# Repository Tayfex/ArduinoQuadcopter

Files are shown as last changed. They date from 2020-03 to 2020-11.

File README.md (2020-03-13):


# Arduino Quadcopter

This project consists of two parts, a flight controller and a remote controller.

## Flight controller

The flight controller runs on the Arduino Uno and is responsible for calculating the quadcopter's current angle and stabilize it from there.
Additionally it takes the remote controller's input so that the user can control the quadcopter.

## Remote controller

The remote controller runs on a computer. The program is written in Processing and is used as the remote controller for the quadcopter. For this purpose the computer is connected to the Arduino running the flight controller via USB.

> **Note:** This is for testing purpose only and might hopefully changed later on as soon as the quadcopter seems to be stable enough for flying.

## Setup

The quadcopter consists of the following parts:

- **Arduino Uno** as flight controller
- **MPU6050** as gyro
- **HC-05** as bluetooth dongle for the drone
- **DJI F450** for the frame

## Wiring

The following pictures shows the wiring of the components.
> **Note:** The battery shown, is not the one used on the drone

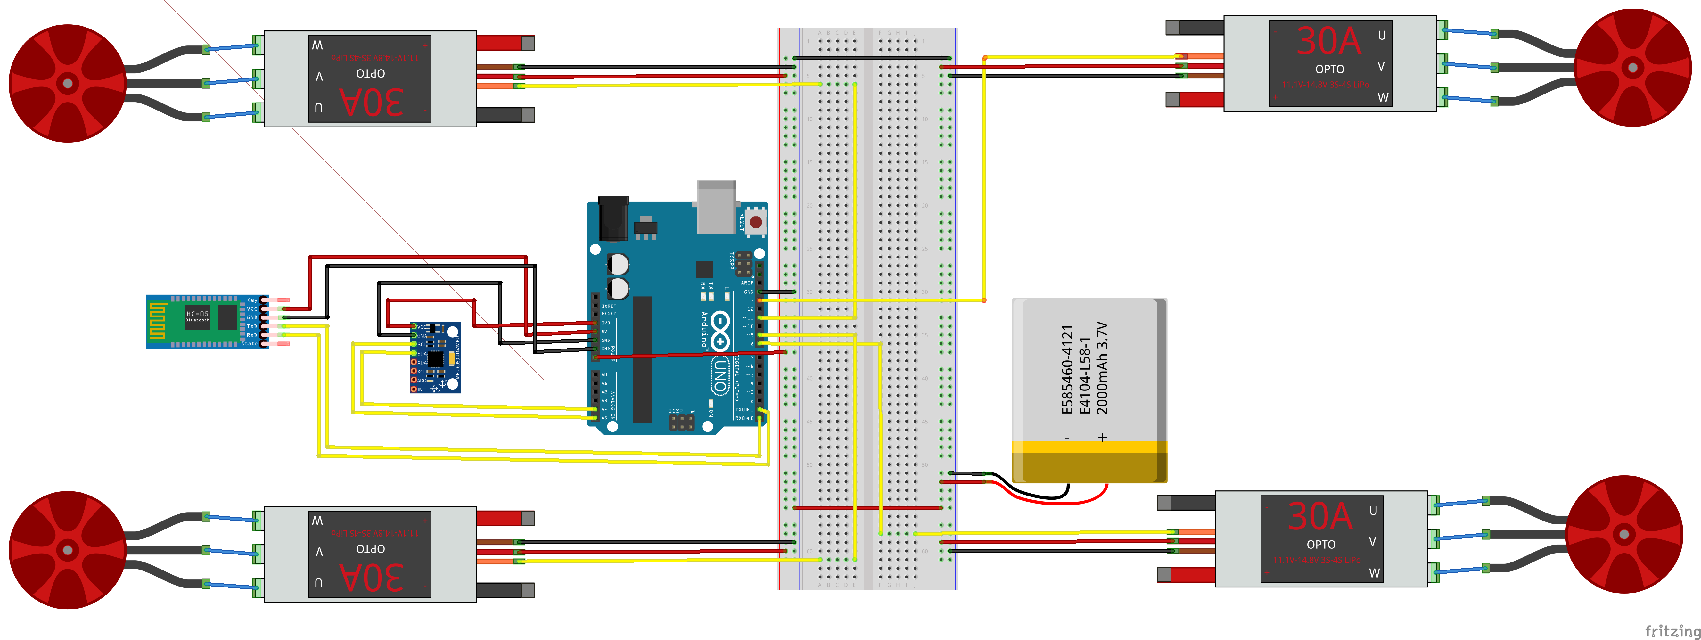
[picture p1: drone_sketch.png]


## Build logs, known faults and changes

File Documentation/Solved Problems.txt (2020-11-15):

Bluetooth Modul in AT Modus hat geholfen, eine stabile Verbindung aufzubauen, die nicht immer wieder abstürtzt. 
Dazu habe ich die Baudrate des Modules auf 115200 angepasst. Zusätzlich auch noch den Namen und Passwort geändert (aber das ist vllt nicht zwangsläufig notwendig)

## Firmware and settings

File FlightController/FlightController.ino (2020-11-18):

#include <Wire.h>
#include <Servo.h>

/* --- SETTINGS --- */

int DISPLAY_VERSION = 2;                            // Which display should be used for the remote controller? 1D or 2D version?

int THROTTLE_MINIMUM = 1000;                        // Minimum throttle of a motor
int THROTTLE_MAXIMUM = 1800;                        // Maximum throttle of a motor

float COMPLEMENTARY_FILTER = 0.98;                   // Complementary filter for combining acc and gyro

double throttle = 1000;                             // Desired throttle
float angle_desired[3] = {0.0, 0.0, 0.0};           // Desired angle

float gain_p[3] = {1.5, 1.5, 1.5};                    // Gain proportional
float gain_i[3] = {0, 0, 0};                        // Gain integral
float gain_d[3] = {0.4, 0.4, 0.4};                    // Gain derivetive

float filter = 0.9;                                 // Complementary filter for pid

int mode = 0;                                       // Mode for testing purpose: 0 = all motors | 1 = motor 1 & 3 | 2 = motor 2 & 4

/* --- CONSTANTS --- */

#define PITCH 0                                     // Rotation forward/backward
#define ROLL 1                                      // Rotation left/right
#define YAW 2                                       // Rotation around center

#define MPU_ADDRESS 0x68

/* --- VARIABLES --- */

float error_current[3] = {0, 0, 0};                 // Current error
float error_prev[3] = {0, 0, 0};                    // Previous error

float pid_current[3] = {0, 0, 0};                   // PID weighted (!) sum of proportional, integral and derivitive error
float pid_p[3] = {0, 0, 0};                         // PID proportional error     
float pid_i[3] = {0, 0, 0};                         // PID integral error
float pid_d[3] = {0, 0, 0};                         // PID derivitive error

float angle_current[3];                             // Angle measured after filtering
float angle_acc[3];                                 // Angle measured using accelerometer
float angle_gyro[3];                                // Angle measured using gyro
float angle_acc_offset[3] = {0.0,0.0,0.0};          // Offsets for gyro angle measurement
float angle_gyro_offset[3] = {0.0,0.0,0.0};         // Offsets for acc angle measurement

float angle_acc_raw[3];                             // Accelerator raw data
int16_t angle_gyro_raw[3];                          // Gyro raw data

float time_current;                                 // Current time
float time_prev;                                    // Previous time
double time_elapsed;                                // Elapsed time during the last loop

Servo motor_1;                                      // Motor front right
Servo motor_2;                                      // Motor front left
Servo motor_3;                                      // Motor back left
Servo motor_4;                                      // Motor back right

float rad_to_deg = 180/3.141592654;                 // Constant for convert radian to degrees

float blink_counter = 0;                            // The blink counter is used to let the build-in LED blink every x loops to see whether the programm is still running or not
bool blink_status = false;                             // Is the build-in LED currently on or off?

float lastCommand = 0;                              // Time when the last comment has been recieved

int sendDataCounter = 0;                            // Counts when data has been sent the last time to reduce amount of data

void setup() {

  /* Begin serial communication for remote control */
  Serial.begin(115200);

  //while(!Serial) {}
  
  Serial.println("SETUP: Start");

  /* Begin the wire communication with the gyro */
  Wire.begin();
  Wire.beginTransmission(MPU_ADDRESS);
  Wire.write(0x6B);
  Wire.write(0);
  Wire.endTransmission(true);

  Serial.println("SETUP: Communication with gyro started");

  /* Set gyro's digital low pass filter to ~5Hz */
  Wire.beginTransmission(MPU_ADDRESS);
  Wire.write(0x1A);
  Wire.write(0x06);
  Wire.endTransmission();

  Serial.println("SETUP: Gyro's low pass filter set");

  time_current = millis();

  /* Attach the motors */
  motor_1.attach(13);                                
  motor_2.attach(11);
  motor_3.attach(9);
  motor_4.attach(8);

  Serial.println("SETUP: Motors attached");

  Serial.println("SETUP: Calibrating motors");

  /* Calibrate the motors */
  calibrateMotors();

  pinMode(13, OUTPUT);

  Serial.println("SETUP: Motors calibrated");
  Serial.println("SETUP: Finished");
}


void loop() {
  /* Calculate elapsed time */
  time_prev = time_current;
  time_current = millis();
  time_elapsed = (time_current - time_prev) / 1000;

  /* Get gyro's data */
  readGyro();
  readAccelerometer();

  /* Filter the data to reduce noise */
  filterAngle();

  /* Receive the remote controller's commands */
  receiveControl();

  /* Calculate PID */
  calculatePid();

  
  if(throttle > 1010) {
    /* Emergency landing if no command has been recieved for more then a second */
    if(millis() > lastCommand + 1000) {
      emergencyLanding();
    }

    /* Apply PID to all motors */
    setMotorPids();
  } else {
    /* Turn off all motors */
    setSpeedForAllMotors(THROTTLE_MINIMUM);
  }

  if(sendDataCounter > 3) {
    /* Send calculated and measured data to the remote controller */
    if(DISPLAY_VERSION == 1) {
      sendData1(ROLL);
    } else if(DISPLAY_VERSION == 2) {
      sendData2();
    }

    sendDataCounter = 0;
  }
  
  sendDataCounter += 1;  

  blinkLED();
}


/**
 * Calculates all PID values
 */
void calculatePid() {
  /* Save previous errors */
  error_prev[PITCH] = error_current[PITCH];
  error_prev[ROLL] = error_current[ROLL];
  error_prev[YAW] = error_current[YAW];

  /* Calculate current error */
  error_current[PITCH] = angle_current[PITCH] - angle_desired[PITCH];
  error_current[ROLL] = angle_current[ROLL] - angle_desired[ROLL];
  error_current[YAW] = angle_current[YAW] - angle_desired[YAW];

  /* Calculate weighted proportional error */
  pid_p[PITCH] = gain_p[PITCH] * error_current[PITCH];
  pid_p[ROLL] = gain_p[ROLL] * error_current[ROLL];
  pid_p[YAW] = gain_p[YAW] * error_current[YAW];

  /* Calculated weighted derivitive error */
  float pid_d_new[3];

  pid_d_new[PITCH] = gain_d[PITCH] * (error_current[PITCH] - error_prev[PITCH]) / time_elapsed;
  pid_d_new[ROLL] = gain_d[ROLL] * (error_current[ROLL] - error_prev[ROLL]) / time_elapsed;
  pid_d_new[YAW] = gain_d[YAW] * (error_current[YAW] - error_prev[YAW]) / time_elapsed;

  pid_d[PITCH] = filter * pid_d[PITCH] + (1 - filter) * pid_d_new[PITCH];
  pid_d[ROLL] = filter * pid_d[ROLL] + (1 - filter) * pid_d_new[ROLL];
  pid_d[YAW] = filter * pid_d[YAW] + (1 - filter) * pid_d_new[YAW];

  /* Calculate weighted sum of the PID */
  pid_current[PITCH] = pid_p[PITCH] + pid_i[PITCH] + pid_d[PITCH];
  pid_current[ROLL] = pid_p[ROLL] + pid_i[ROLL] + pid_d[ROLL];
  pid_current[YAW] = pid_p[YAW] + pid_i[YAW] + pid_d[YAW];
}


/* 
* Sets the PID values to motors 
* THERE MIGHT BE SOME ERRORS WITH THE SIGNS of the pid variables
* TODO: Write down the orientation 
*/
void setMotorPids() {
  if(mode == 1 || mode == 0) {
    motor_1.writeMicroseconds(throttle + pid_current[PITCH] + pid_current[ROLL] + pid_current[YAW]);      // Set PID for front right motor
    motor_3.writeMicroseconds(throttle - pid_current[PITCH] - pid_current[ROLL] + pid_current[YAW]);      // Set PID for back left motor
  }

  if(mode == 2 || mode == 0) {
    motor_2.writeMicroseconds(throttle + pid_current[PITCH] - pid_current[ROLL] - pid_current[YAW]);      // Set PID for front left motor
    motor_4.writeMicroseconds(throttle - pid_current[PITCH] + pid_current[ROLL] - pid_current[YAW]);      // Set PID for back right motor
  }
}

/*
 * Automatic emergency landing:
 * Decrease throttle slowly and set desired angle to 0
 */
void emergencyLanding() {
  throttle = throttle - 0.25;
      
  angle_desired[0] = 0.0;
  angle_desired[1] = 0.0;
  angle_desired[2] = 0.0;
}

/**
 * Calibrates all 4 motors
 */
void calibrateMotors() {
  setSpeedForAllMotors(THROTTLE_MINIMUM);
  delay(7000);
}


/**
 * Sets the given speed for all motors
 */
void setSpeedForAllMotors(double speed) {
  motor_1.writeMicroseconds(speed);
  motor_2.writeMicroseconds(speed);
  motor_3.writeMicroseconds(speed);
  motor_4.writeMicroseconds(speed);
}

/**
 * Let the build-in status LED blink to make sure the main loop is running and not stuck
 */
void blinkLED() {
  if(blink_counter > 20) {
    blink_status = !blink_status;

    // Toggle LED
    if(blink_status) {
      digitalWrite(13, HIGH);
    }
    else {
      digitalWrite(13, LOW);
    }
    
    blink_counter = 0;
  }

  blink_counter = blink_counter + 1;  
}

/**
 * Low pass filter the gyro's data using a complementary filter 
 */
void filterAngle() {
  float angle_new[3];

  angle_new[PITCH] = -(COMPLEMENTARY_FILTER * (-angle_current[PITCH] + angle_gyro[PITCH] * time_elapsed) + (1 - COMPLEMENTARY_FILTER) * angle_acc[PITCH]);    // Positive angle -> forward
  angle_new[ROLL] = COMPLEMENTARY_FILTER * (angle_current[ROLL] + angle_gyro[ROLL] * time_elapsed) + (1 - COMPLEMENTARY_FILTER) * angle_acc[ROLL];            // Positive angle -> right
  angle_new[YAW] = COMPLEMENTARY_FILTER * (angle_current[YAW] + angle_gyro[YAW] * time_elapsed) + (1 - COMPLEMENTARY_FILTER) * angle_acc[YAW];                // Calculated by chris

  float value = 0.5; // some weird stuff is going on here, this is we we use the value variable

  angle_current[PITCH] = value * angle_current[PITCH] + (1 - value) * angle_new[PITCH];
  angle_current[ROLL] = value * angle_current[ROLL] + (1 - value) * angle_new[ROLL];
  angle_current[YAW] = value * angle_current[YAW] + (1 - value) * angle_new[YAW];
}


/**
 * Reads the gyro and saves the values
 */
void readGyro() {
  /* Ask gyro for gyro data */
  Wire.beginTransmission(MPU_ADDRESS);
  Wire.write(0x43);
  Wire.endTransmission(false);
  Wire.requestFrom(MPU_ADDRESS, 6, true);

  /* Save received answer */
  angle_gyro_raw[PITCH] = Wire.read()<<8|Wire.read();
  angle_gyro_raw[ROLL] = Wire.read()<<8|Wire.read();
  angle_gyro_raw[YAW] = Wire.read()<<8|Wire.read();         // Added, did not check if that works

  /* Convert the data to degrees */
  angle_gyro[PITCH] = angle_gyro_raw[PITCH] / 131.0;
  angle_gyro[ROLL] = angle_gyro_raw[ROLL] / 131.0;
  angle_gyro[YAW] = angle_gyro_raw[YAW] / 131.0;              // Added, did not check if that works

  /* Subtract gyro offset value, this is done here, because the total angle is calculated by integration */
  angle_gyro[PITCH] = angle_gyro[PITCH] - angle_gyro_offset[PITCH];
  angle_gyro[ROLL] = angle_gyro[ROLL] - angle_gyro_offset[ROLL];
  angle_gyro[YAW] = angle_gyro[YAW] - angle_gyro_offset[YAW];
}


/**
 *  Reads the accelerometer and saves the values
 */
void readAccelerometer() {
  /* Ask gyro for acceleration data */
  Wire.beginTransmission(MPU_ADDRESS);
  Wire.write(0x3B);
  Wire.endTransmission(false);
  Wire.requestFrom(MPU_ADDRESS, 6, true);

  /* Save received answer */
  angle_acc_raw[PITCH] = (Wire.read()<<8|Wire.read()) / 16384.0;
  angle_acc_raw[ROLL] = (Wire.read()<<8|Wire.read()) / 16384.0;
  angle_acc_raw[YAW] = (Wire.read()<<8|Wire.read()) / 16384.0;

  /* Convert the data to g */
  angle_acc[PITCH] = atan(angle_acc_raw[ROLL] / sqrt(pow(angle_acc_raw[PITCH], 2) + pow(angle_acc_raw[YAW], 2))) * rad_to_deg;
  angle_acc[ROLL] = atan(-1 * angle_acc_raw[PITCH] / sqrt(pow(angle_acc_raw[ROLL], 2) + pow(angle_acc_raw[YAW], 2))) * rad_to_deg;
  angle_acc[YAW] = atan(angle_acc_raw[PITCH] / angle_acc_raw[ROLL]);
  //angle_acc[YAW] = angle_acc_raw[YAW] / 16384.0;                   // Calculated by my own, don't know if its correct...

  /* Subtract Acc angle offsets, this is done here, since the total angle is calculated by integration and offsets there interfere with integration */
  angle_acc[PITCH] = angle_acc[PITCH] - angle_acc_offset[PITCH];
  angle_acc[ROLL] = angle_acc[ROLL] - angle_acc_offset[ROLL];
  angle_acc[YAW] = angle_acc[YAW] - angle_acc_offset[YAW];
}


/**
 *  Takes 100 samples of current angle measurement and takes average as new offset
 */
void calibrateAngleOffsets() {
  float num = 100.0;
  float gyro_avg[3] = {0.0,0.0,0.0};
  float acc_avg[3] = {0.0,0.0,0.0};
  for(int i = 0; i < num; i++){
    // Read Gyro angles and add to average
    readGyro();
    gyro_avg[PITCH] += angle_gyro[PITCH];
    gyro_avg[ROLL] += angle_gyro[ROLL];
    gyro_avg[YAW] += angle_gyro[YAW];
    
    // Read ACC angles and add to average
    readAccelerometer();
    acc_avg[PITCH] += angle_acc[PITCH];
    acc_avg[ROLL] += angle_acc[ROLL];
    acc_avg[YAW] += angle_acc[YAW];
  }

  // divide sums by number of measurements to get average
  angle_gyro_offset[PITCH] = gyro_avg[PITCH] / num;
  angle_gyro_offset[ROLL] = gyro_avg[ROLL] / num;
  angle_gyro_offset[YAW] = gyro_avg[YAW] / num;
  angle_acc_offset[PITCH] = acc_avg[PITCH] / num;
  angle_acc_offset[ROLL] = acc_avg[ROLL] / num;
  angle_acc_offset[YAW] = acc_avg[YAW] / num;
}


/**
 * Receive remote control's command
 * 
 * There are two kind of commands: increase/decrease some value or it's direct value.
 * Direct value commands start with a '.'
 * Each command is determinated with ';'
 */
void receiveControl() {
  if(Serial.available()) {
    // Read until end of command
    String command = Serial.readStringUntil(';');

    if(command[0] == '.') {
      // Receive direct value command

      if(command[1] == 't') {
        throttle = command.substring(2).toInt();                    // Set throttle to value
      } else if(command[1] == 'p') {
        angle_desired[PITCH] = command.substring(2).toFloat();      // Set desired PITCH
      } else if(command[1] == 'r') {
        angle_desired[ROLL] = command.substring(2).toFloat();       // Set Desired ROLL
      } else if(command[1] == 'y') {
        angle_desired[YAW] = command.substring(2).toFloat();        // Set desired YAW
      }

      lastCommand = millis();
    } else {
      // Receive increase/decrease command

      if(command == "throttle+") {
        throttle += 50;                                             // Increase throttle

        if(throttle >= THROTTLE_MAXIMUM) {
          throttle = THROTTLE_MAXIMUM;
        }
      } else if(command == "throttle-") {
        throttle -= 50;                                             // Decrease throttle

        if(throttle <= THROTTLE_MINIMUM) {
          throttle = THROTTLE_MINIMUM;
        }
      } else if(command == "stop") {
        throttle = THROTTLE_MINIMUM;                                // Turn off all motors
      } else if(command == "calibrateAngles") {
        calibrateAngleOffsets();                                    // Calibrate gyro and accelerometer offsets
      } else if(command == "gainP+") {
        gain_p[PITCH] = gain_p[PITCH] + 0.1;                        // Increase P gain for pitch
        gain_p[ROLL] = gain_p[ROLL] + 0.1;                          // Increase P gain for roll
      } else if(command == "gainP-") {
        gain_p[PITCH] = gain_p[PITCH] - 0.1;                        // Decrease P gain for pitch
        gain_p[ROLL] = gain_p[ROLL] - 0.1;                          // Decrease P gain for roll
      } else if(command == "gainD+") {
        gain_d[PITCH] = gain_d[PITCH] + 0.05;                       // Increase D gain for pitch
        gain_d[ROLL] = gain_d[ROLL] + 0.05;                         // Increase D gain for roll
      } else if(command == "gainD-") {
        gain_d[PITCH] = gain_d[PITCH] - 0.05;                       // Decrease D gain for pitch
        gain_d[ROLL] = gain_d[ROLL] - 0.05;                         // Decrease D gain for roll
      } else if(command == "right") {
        angle_desired[ROLL] = angle_desired[ROLL] + 2;              // Move right
      } else if(command == "left") {
        angle_desired[ROLL] = angle_desired[ROLL] - 2;              // Move left
      } else if(command == "filter+") {
        filter = filter + 0.005;                                    // Increase complementary filter
      } else if(command == "filter-") {
        filter = filter - 0.005;                                    // Decrease complementary filter
      } else if(command == "mode0") {
        mode = 0;                                                   // Activate all motors
      } else if(command == "mode1") {
        mode = 1;                                                   // Activate motor 1 & 3
      } else if(command == "mode2") {
        mode = 2;                                                   // Activate motor 2 & 4
      }
    }
  }
}


/**
 * Sends the controller's settings and measured data for one dimension to the remote controller
 */
void sendData1(int angleType) {
  Serial.println("B1" + 
    String(throttle) + "|" + 
    String(angle_current[angleType]) + "|" + 
    String(angle_desired[angleType]) + "|" + 
    String(pid_current[angleType]) + "|" + 
    String(pid_p[angleType]) + "|" + 
    String(pid_d[angleType]) + "|" + 
    String(gain_p[angleType]) + "|" + 
    String(gain_d[angleType], 3) + "|" + 
    String(time_elapsed, 6) + "|" + 
    String(filter, 3) + "|" + 
    String(angle_gyro[angleType], 6) + "|" + 
    String(angle_acc[angleType], 6) + "|" + 
    String(mode) + "E");
}

/**
 * Sends the controller's settings and measured data for two dimensions to the remote controller
 */
void sendData2() {
  Serial.println("B2" +
    String(throttle) + "|" + 
    String(angle_current[PITCH]) + "|" + 
    String(angle_current[ROLL]) + "|" + 
    String(angle_current[YAW]) + "|" + 
    String(angle_desired[PITCH]) + "|" +
    String(angle_desired[ROLL]) + "|" +
    String(pid_current[PITCH]) + "|" + 
    String(pid_current[ROLL]) + "|" + 
    String(gain_p[PITCH]) + "|" + 
    String(gain_d[PITCH], 3) + "|" + 
    String(angle_gyro[PITCH], 6) + "|" + 
    String(angle_gyro[ROLL], 6) + "|" +
    String(angle_acc[PITCH], 6) + "|" +
    String(angle_acc[ROLL], 6) + "E");
}

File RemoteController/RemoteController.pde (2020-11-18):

import net.java.games.input.*;
import org.gamecontrolplus.*;
import org.gamecontrolplus.gui.*;

import processing.serial.*;


// --- SETTINGS ---

int WINDOW_SIZE_X = 1120;               // Window width
int WINDOW_SIZE_Y = 500;                // Window height

int RECT_BAR_SIZE_X = 100;              // Rect bar width
int RECT_BAR_SIZE_Y = 300;              // Rect bar height

int PORT_NUMBER = 2;                    // Index of the serial port
int GRAPH_ZOOM = 3;                     // Zoom of the graph

// --- VARIABLES ---

float displayVersion = 2;               // 1D or 2D display
float throttle = 1000;                  // Current throttle
float angle_current_roll = 0;           // Current roll angle
float angle_current_pitch = 0;          // Current pitch angle
float angle_current_yaw = 0;            // Current yaw angle
float angle_desired_roll = 0;           // Desired roll angle
float angle_desired_pitch = 0;          // Desired pitch angle
float pid_current_roll = 0;             // Total PID value for roll
float pid_current_pitch = 0;            // Total PID value for pitch
float pid_p = 0;                        // PID P value
float pid_d = 0;                        // PID D value
float gain_p = 0;                       // PID P gain
float gain_d = 0;                       // PID D gain
float time_elapsed = 0;                 // Elapsed time
float filter = 0;                       // Filter strength
float angle_gyro_roll = 0;              // Gyro value for roll
float angle_gyro_pitch = 0;             // Gyro value for pitch
float angle_acc_roll = 0;               // Accelerometer value for roll
float angle_acc_pitch = 0;              // Accelerometer value for pitch

int throttleGamepad = 0;

FloatList graph1;                       // Gyro history
FloatList graph2;                       // Acc history
FloatList graph3;                       // Angle history

Serial port;                            // Port for serial communication
String portStream;                      // Port input stream

PFont f;                                // GUI font

int calibrateSend = 0;                  // Time a calibrate command has been send or 0
int sendInput = 0;

boolean setupFinished = false;          // True as soon as loading has finished

ControlDevice controller;               // Gamepad controller
ControlIO control;


// --- PROGRAM ---

void setup() {
  // Initialize lists
  graph1 = new FloatList();
  graph2 = new FloatList();
  graph3 = new FloatList();

  // Load font
  f = createFont("Arial", 50, true); 
  textFont(f, 50);
  textAlign(CENTER);

  // Prepare window
  size(1120, 750);
  fill(0, 0, 0);
  drawDisplay();

  // Display loading screen
  drawInfoBox("Loading");

  // Start communication with Arduino
  printArray(Serial.list());
  port = new Serial(this, Serial.list()[PORT_NUMBER], 115200);

  println("Looking for gamepad");

  // Start communication with gamepad
  control = ControlIO.getInstance(this);
  println("Looking for gamepad");
  println(control.deviceListToText("---"));
  controller = control.filter(GCP.GAMEPAD).getMatchedDevice("xboxController");
  //controller = control.getDevice(4);
  
  if (controller == null) {
    println("Gamepad not found");
    System.exit(-1); // End the program NOW!
  }

  // Check if gamepad has been found
  if (controller == null) {
    println("Gamepad not found");
    System.exit(-1);
  } else {
    println("Gamepad found");
  }
}

void draw() {
  // Draw info box if calibration has been send
  if(calibrateSend != 0) {
    if(millis() > calibrateSend + 1000) {
      calibrateSend = 0; 
    } else {
      drawInfoBox("Calibrate send");
      return;
    }
  }
  
  // Redraw display whenever recieving new data
  if (port.available() > 100) {

    // Read port stream
    portStream = port.readString();
    String dataString = findDataInString(portStream);

    // ----- Drone in FLY MODE -----
    if (dataString != "") {
      
      println(dataString);

      // Save recieved data
      String[] data = split(dataString.substring(2, dataString.length() - 1), '|');

      // Check if recieved data are complete
      if (data.length > 12) {

        // Unpack data
        if(dataString.charAt(1) == '1') {
          displayVersion = 1;
        } else if(dataString.charAt(1) == '2') {
          displayVersion = 2; 
        }
        
        if(displayVersion == 1) {
          
          // Unpack data according to 1D display verion
          throttle = float(data[0]);
          angle_current_pitch = float(data[1]);
          angle_desired_pitch = float(data[2]);
          pid_current_pitch = float(data[3]);
          pid_p = float(data[4]);
          pid_d = float(data[5]);
          gain_p = float(data[6]);
          gain_d = float(data[7]);
          time_elapsed = float(data[8]);
          filter = float(data[9]);
          angle_gyro_pitch = float(data[10]);
          angle_acc_pitch = float(data[11]);
          
        } else if(displayVersion == 2) {
          
          // Unpack data according to 2D display version
          throttle = float(data[0]);
          angle_current_pitch = float(data[1]);
          angle_current_roll = float(data[2]);
          angle_current_yaw = float(data[3]);
          angle_desired_pitch = float(data[4]);
          angle_desired_roll = float(data[5]);
          pid_current_pitch = float(data[6]);
          pid_current_roll = float(data[7]);
          gain_p = float(data[8]);
          gain_d = float(data[9]);
          angle_gyro_pitch = float(data[10]);
          angle_gyro_roll = float(data[11]);
          angle_acc_pitch = float(data[12]);
          angle_acc_roll = float(data[13]);
        }

        // Redraw display
        drawDisplay();
      } else {

        // Print error
        log("ERROR 1 | Data incomplete: " + portStream);
      }
    }
    else {
       log("ERROR 2 | Data incomplete: " + portStream);
    }
  }
  else {
    log("ERROR 3 | Not enough data yet: " + port.available());
  }
  
  //sendGamepadInput();
  if(sendInput > 3) {
      sendGamepadInput();
      sendInput = 0;
    }
    
    sendInput += 1;
}

void log(String message) {
  println("[" + millis() + "] " + message);
}

/*
  Find the actual data in the given string
*/
String findDataInString(String data) {
  int start = data.indexOf("B");
  int end = data.indexOf("E", start);
  
  if(start != -1 && end != -1) {
    return data.substring(start, end + 1);
  }
  
  return "";
}
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

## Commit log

2020-02-06 install servo lib
2020-02-08 Adjusted motor setup
    Motors have been reorganized and the PID controller has been adjusted to their correct positions (front, back, left, right)
    [FlightController.ino]
2020-02-09 updated servo connections due to new soldering
2020-02-09 Corrected readGyro
    Amount of requested bytes has been corrected
    [FlightController.ino]
2020-02-09 added simple complementary filter for angle and pid_d
2020-03-01 Gamepad added
    + control quadcopter with gamepad in processing
    * communication processing to arduino reworked
    [FlightController.ino, RemoteController.pde]
2020-03-01 Updated Remote Controller display \n\n Tryed to improve the remote controller's display but a bug is slowing down the program a lot
    [FlightController.ino, RemoteController.pde]
2020-03-03 Gamepad working
    * Fixed bug (buffer overflow) that slowed down remote controller
    * Gamepad is working fine now
    [FlightController.ino, RemoteController.pde]
2020-03-11 2D display added
    + 2D display added
    + Arduino to Processing communication extended for new display
    + Xbox controller support extended with second input stick
2020-03-13 remove motor calibration
2020-03-13 Extended gamepad controller
    + Gamepad can be used for throttle and direction
    + Gamepad mapping extended with new buttons
2020-03-13 angle calibration functionality
2020-03-13 direct input for pitch, roll and yaw
2020-03-13 added wiring sketch to readme
    [drone_sketch.fzz]
2020-03-13 Gamepad working
    + Fixed some small bugs
    + Added UI for calibration
    [RemoteController.pde]
2020-11-15 Fixed bluetooth
    Bluetooth has been fixed (information has been added in file)
    [FlightController.ino, RemoteController.pde]
2020-11-18 Changed filter
    The low-pass filter has been changed to 5 Hz which seems to make the quadcopter quite stable!
    At least the measurements fit much better then before!
2020-11-18 Added yaw
    Yaw control has been added to the drone
